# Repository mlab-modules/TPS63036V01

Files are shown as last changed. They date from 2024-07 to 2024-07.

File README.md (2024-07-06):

# TPS63036V01 -  TPS63036-Based  buck-boost converter 

The TPS63036V01 module is a highly efficient, single-inductor, buck-boost converter designed to provide a stable output voltage from varying input voltages. It integrates the Texas Instruments TPS63036 chip, making it suitable for applications requiring a compact, efficient power solution.

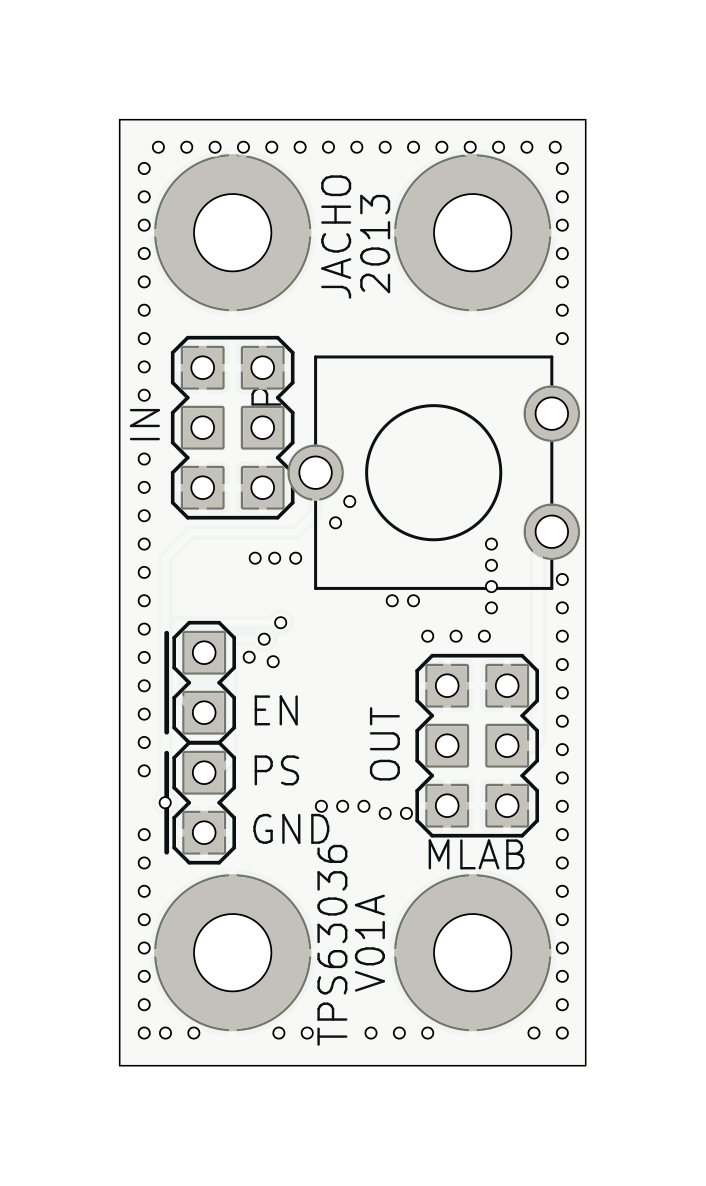
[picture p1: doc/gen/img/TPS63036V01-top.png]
TPS63036V01 top

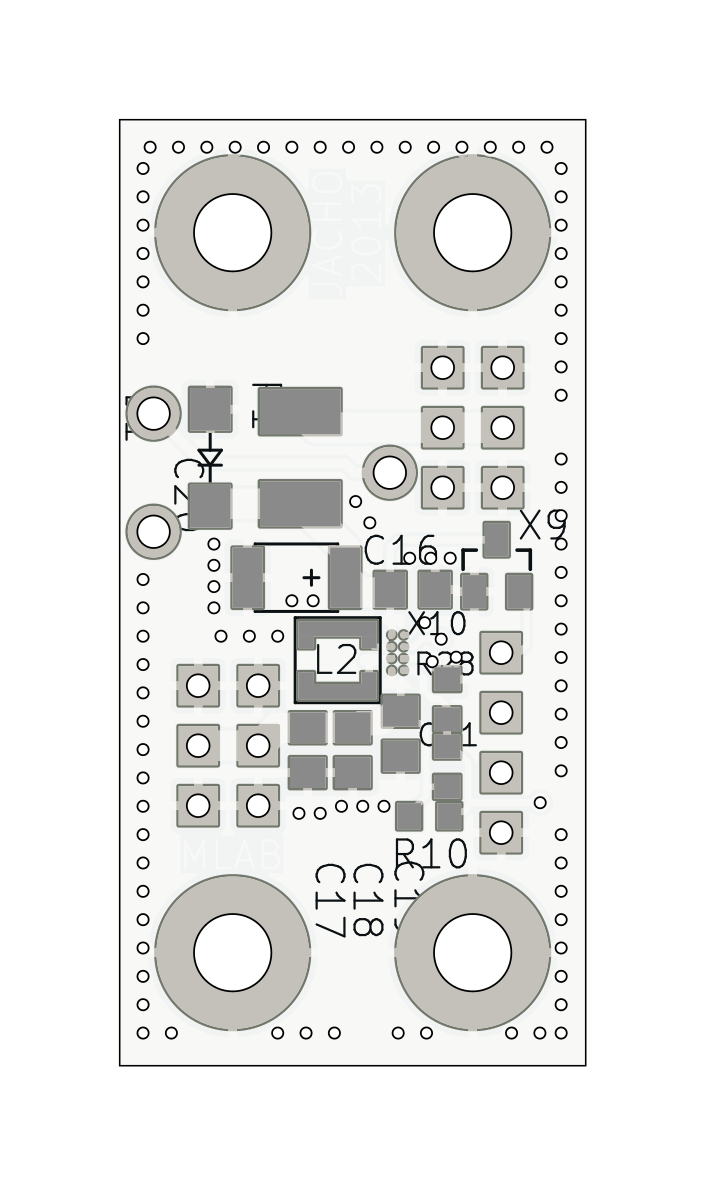
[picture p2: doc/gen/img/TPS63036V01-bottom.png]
TPS63036V01 bottom


## Features

- **Input Voltage Range:** 1.8V to 5.5V
- **Output Voltage:** 3.3V (adjustable between 1.2V and 5.5V)
- **Maximum Output Current:** 600 mA
- **Operating Frequency:** 2 MHz
- **High Efficiency:** Up to 85% at 3.6V input and 500mA load
- **Compact Size:** Miniature 3.0 × 3.0 mm footprint
- **Shielded Inductors:** LPS3015 series for low DCR and excellent current handling

## Components

### TPS63036 Buck-Boost Converter
- **Manufacturer:** Texas Instruments
- **Package:** 8-ball, 1.854 mm × 1.076 mm wafer chip-scale package (YFG)
- **Description:** The TPS63036 is a highly efficient single-inductor buck-boost converter. It supports both fixed and adjustable output voltages. The device operates with an input voltage range of 1.8V to 5.5V.

### LPS3015 Series Shielded Inductors
- **Manufacturer:** Coilcraft
- **Inductance Values:** Range from 1.0 µH to 330 µH
- **DCR (max):** 0.075 to 23.0 ohms
- **Current Rating:** Up to 2.35A
- **SRF (min):** 9 MHz
- **Dimensions:** 3.0 × 3.0 mm footprint, less than 1.5 mm tall

## Setup Instructions

1. **Input Connection:** Connect the input power supply between on input header. Ensure the input voltage is between 1.8V and 5.5V.
2. **Output Connection:** Connect the load to output header.
3. **Enable/Disable:** Use jumper SV1 to enable or disable the TPS63036.
4. **Power-Saving Mode:** Use jumper SV6 to enable (PWM/PSM) or disable (PWM) the power-saving mode.

## Performance Specifications

| Parameter | Condition | Min  | Typ  | Max  | Unit |
|---|---|---|---|---|---|
| Input Voltage | | 1.8  | 5.5  | | V |
| Output Voltage  | Vin = 4.2V, Iout = 500mA | 3.2  | 3.3  | 3.4  | V |
| Output Current  | Vin = 3.6V | 0 | 600  | | mA |
| Operating Freq. | | | 2000 | | kHz  |
| Efficiency | 3.6V in, 500mA load | | 85 | | % |
| Output Ripple | 3.6V in, 500mA load | | 25 | | mV |

## Additional Resources

- [TPS63036 Datasheet](https://www.ti.com/lit/ds/symlink/tps63036.pdf)
- [LPS3015 Inductor Datasheet](https://www.coilcraft.com/en-us/products/inductors/shielded/lps3015/)

## Contact

For support, contact MLAB at [support@mlab.cz](mailto:support@mlab.cz).

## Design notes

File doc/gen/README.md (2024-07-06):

# PCB

Board size: 19.81x40.13 mm (0.78x1.58 inches)

- This is the size of the rectangle that contains the board
- Thickness: 1.6 mm (63 mils)
- Material: FR4
- Finish: HAL
- Layers: 2
- Copper thickness: 35 µm

Solder mask: TOP / BOTTOM

- Color: Green

Silk screen: TOP / BOTTOM

- Color: White

# Important sizes

Clearance: 0.15 mm (6 mils)

Track width: 0.25 mm (10 mils)

- By design rules: 0.0 mm (0 mils)

Drill: 0.5 mm (20 mils)

- Vias: 0.5 mm (20 mils) [Design: 0.4 mm (16 mils)]
- Pads: 1.0 mm (39 mils)
- The above values are real drill sizes, they add 0.1 mm (4 mils) to plated holes (PTH)

Via: 0.81/0.4 mm (32/16 mils)

- By design rules: 0.5/0.3 mm (20/12 mils)
- Micro via: yes [0.2/0.1 mm (8/4 mils)]
- Buried/blind via: yes
- Total: 100 (thru: 100 buried/blind: 0 micro: 0)

Outer Annular Ring: 0.15 mm (6 mils)

- By design rules: 0.33 mm (13 mils)

Eurocircuits class: 6B
- Using min drill 0.5 mm for an OAR of 0.15 mm

# General stats

Components count: (SMD/THT)

- Top: 0/9 (THT)
- Bottom: 0/13 (THT)

Defined tracks:

Used tracks:

- 0.25 mm (10 mils) (61) defined: no
- 0.3 mm (12 mils) (13) defined: no
- 0.41 mm (16 mils) (9) defined: no
- 1.02 mm (40 mils) (7) defined: no
- 1.27 mm (50 mils) (14) defined: no

Defined vias:

Used vias:

- 0.81/0.4 mm (32/16 mils) (Count: 100, Aspect: 2.0 A) defined: no

Holes (excluding vias):

- 0.89 mm (35 mils) (16)
- 1.3 mm (51 mils) (3)
- 3.2 mm (126 mils) (4)

Oval holes:

Drill tools (including vias and computing adjusts and rounding):

- 0.5 mm (20 mils) (100)
- 1.0 mm (39 mils) (16)
- 1.4 mm (55 mils) (3)
- 3.3 mm (130 mils) (4)

Solder paste stats:

Using a paste with 87.75 % alloy, that has an specific gravity for the alloy of 7.4 g/cm³
and 1.0 g/cm³ for the flux. This paste has an specific gravity of  4.15 g/cm³.

The stencil thickness is  0.12 mm.

| Side | Pads with paste | Area [mm²] | Paste [g] |
|---|---|---|---|
| Total  | 29 | 57.42 | 0.29 |

Note: this is just an approximation to the theoretical value. Margins of the solder mask and waste aren't computed.

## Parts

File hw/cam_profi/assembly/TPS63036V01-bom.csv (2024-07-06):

Component | Description | Part | References | Value | Footprint | Quantity Per PCB | Datasheet
1 |  | C0603 | C21 | 10p | 0603 | 1
2 |  | C0805 | C16C17C18C19 | 10uF | C0805 | 4
3 |  | B | C20 | 47uF | B | 1
4 |  | D-OB.SMA | D1 | D-OB.SMA | SMA | 1
5 |  | LPS3015 | L2 | LPS3015-152MLC | LPS3015 | 1
6 |  | POJISTKA_1812 | P1 | POJISTKA_1812 | 1812 | 1
7 |  | TRIM_CA9MTV10 | P2 | TRIM_CA9MTV10 | TRIM_CA9MTV10 | 1
8 |  | R0603 | R28 | 51k1 | 0603 | 1
9 |  | R0603 | R10 | 287k | 0603 | 1
10 |  | MA02-1 | SV1SV6 | MA02-1 | MA02-1 | 2
11 |  | MA03-2 | SV3SV5 | MA03-2 | MA03-2 | 2
12 |  | APX809-26SA | X9 | APX809-26SA | SOT23 | 1
13 |  | SROUB3M | X1X2X3X4 | SROUB3M | SROUB3M | 4
14 |  | TPS63036 | X10 | TPS63036 | DSBGA8 | 1

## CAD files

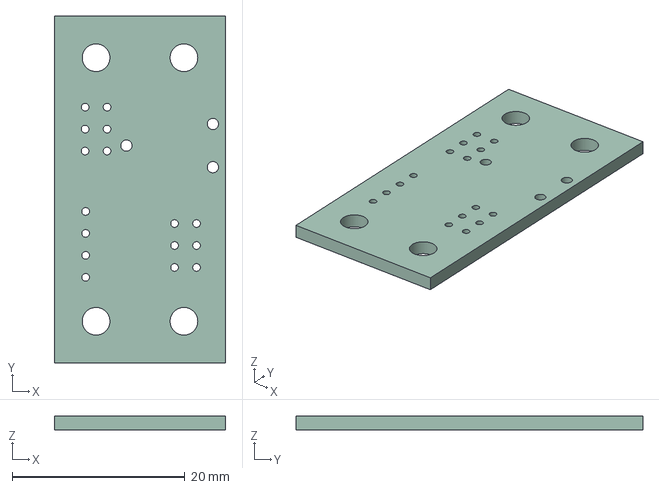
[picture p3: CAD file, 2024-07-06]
doc/gen/TPS63036V01.step
19.8 x 40.1 x 1.60 mm

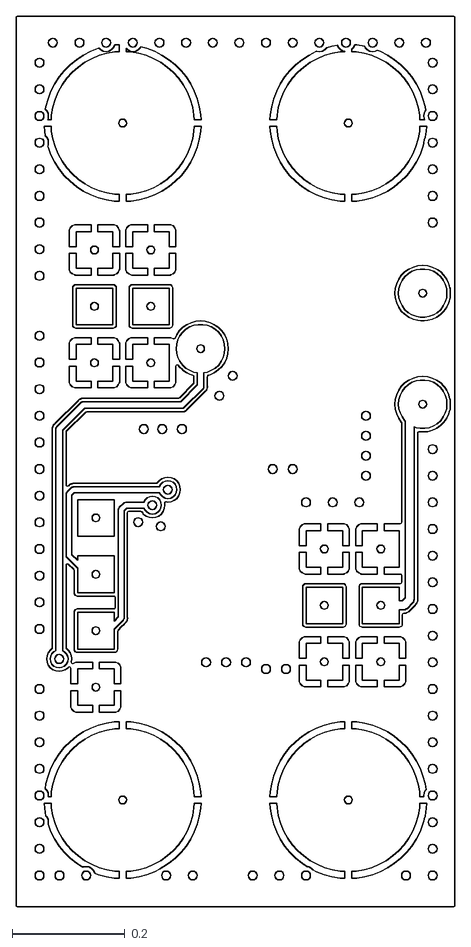
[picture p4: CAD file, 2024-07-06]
doc/gen/dxf/TPS63036V01-F_Cu.dxf
0.778 x 1.58

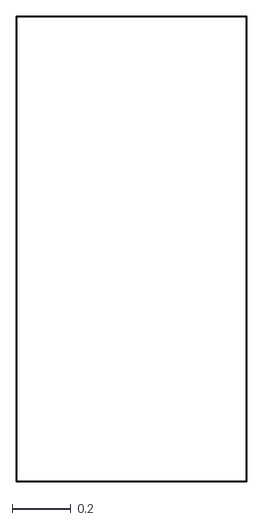
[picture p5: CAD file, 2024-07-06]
doc/gen/dxf/TPS63036V01-Edge_Cuts.dxf
0.782 x 1.58

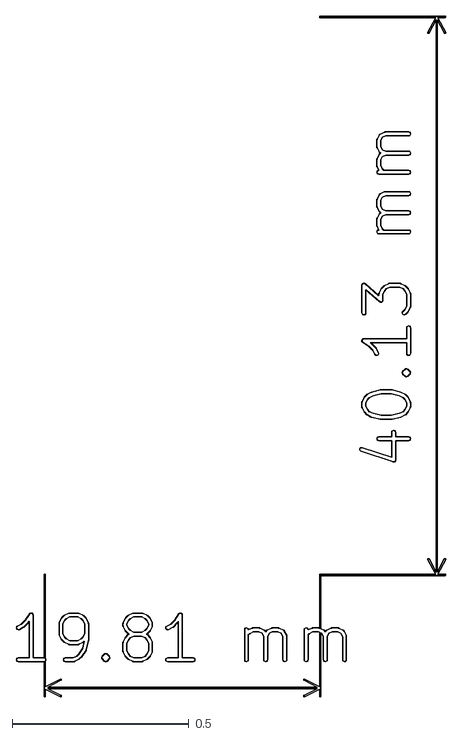
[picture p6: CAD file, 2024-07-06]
doc/gen/dxf/TPS63036V01-User_Comments.dxf
1.22 x 1.93

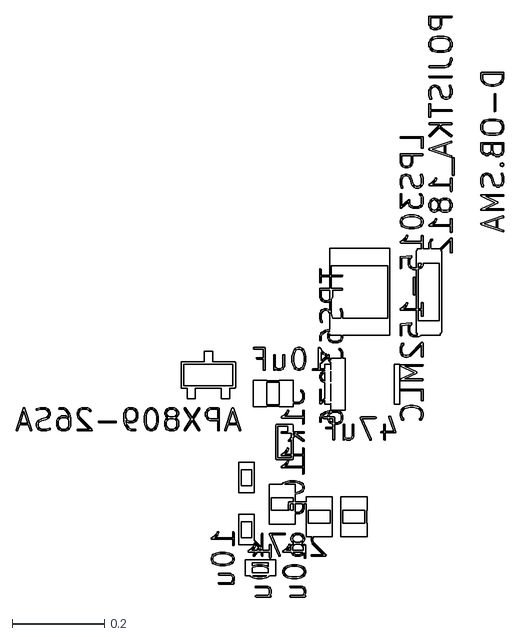
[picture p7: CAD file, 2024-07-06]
doc/gen/dxf/TPS63036V01-B_Fab.dxf
1.06 x 1.26

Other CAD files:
doc/gen/dxf/TPS63036V01-User_Eco2.dxf
doc/gen/dxf/TPS63036V01-User_8.dxf
doc/gen/dxf/TPS63036V01-User_5.dxf
doc/gen/dxf/TPS63036V01-F_Courtyard.dxf
doc/gen/dxf/TPS63036V01-Margin.dxf
doc/gen/dxf/TPS63036V01-F_Adhesive.dxf
doc/gen/dxf/TPS63036V01-User_1.dxf
doc/gen/dxf/TPS63036V01-User_6.dxf
doc/gen/dxf/TPS63036V01-User_3.dxf
doc/gen/dxf/TPS63036V01-User_2.dxf
doc/gen/dxf/TPS63036V01-B_Courtyard.dxf
doc/gen/dxf/TPS63036V01-B_Adhesive.dxf
doc/gen/dxf/TPS63036V01-User_7.dxf
doc/gen/dxf/TPS63036V01-B_Cu.dxf
doc/gen/dxf/TPS63036V01-B_Mask.dxf
doc/gen/dxf/TPS63036V01-B_Paste.dxf
doc/gen/dxf/TPS63036V01-B_Silkscreen.dxf
doc/gen/dxf/TPS63036V01-F_Fab.dxf
doc/gen/dxf/TPS63036V01-F_Mask.dxf
doc/gen/dxf/TPS63036V01-F_Paste.dxf
doc/gen/dxf/TPS63036V01-F_Silkscreen.dxf
doc/gen/dxf/TPS63036V01-User_4.dxf
doc/gen/dxf/TPS63036V01-User_9.dxf
doc/gen/dxf/TPS63036V01-User_Drawings.dxf
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

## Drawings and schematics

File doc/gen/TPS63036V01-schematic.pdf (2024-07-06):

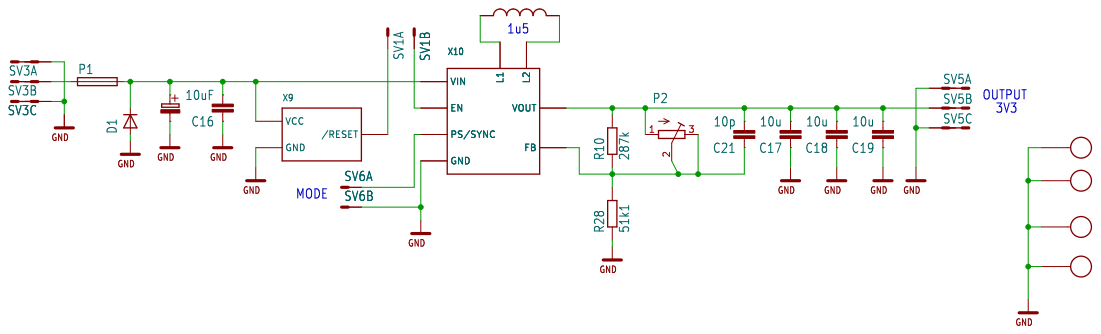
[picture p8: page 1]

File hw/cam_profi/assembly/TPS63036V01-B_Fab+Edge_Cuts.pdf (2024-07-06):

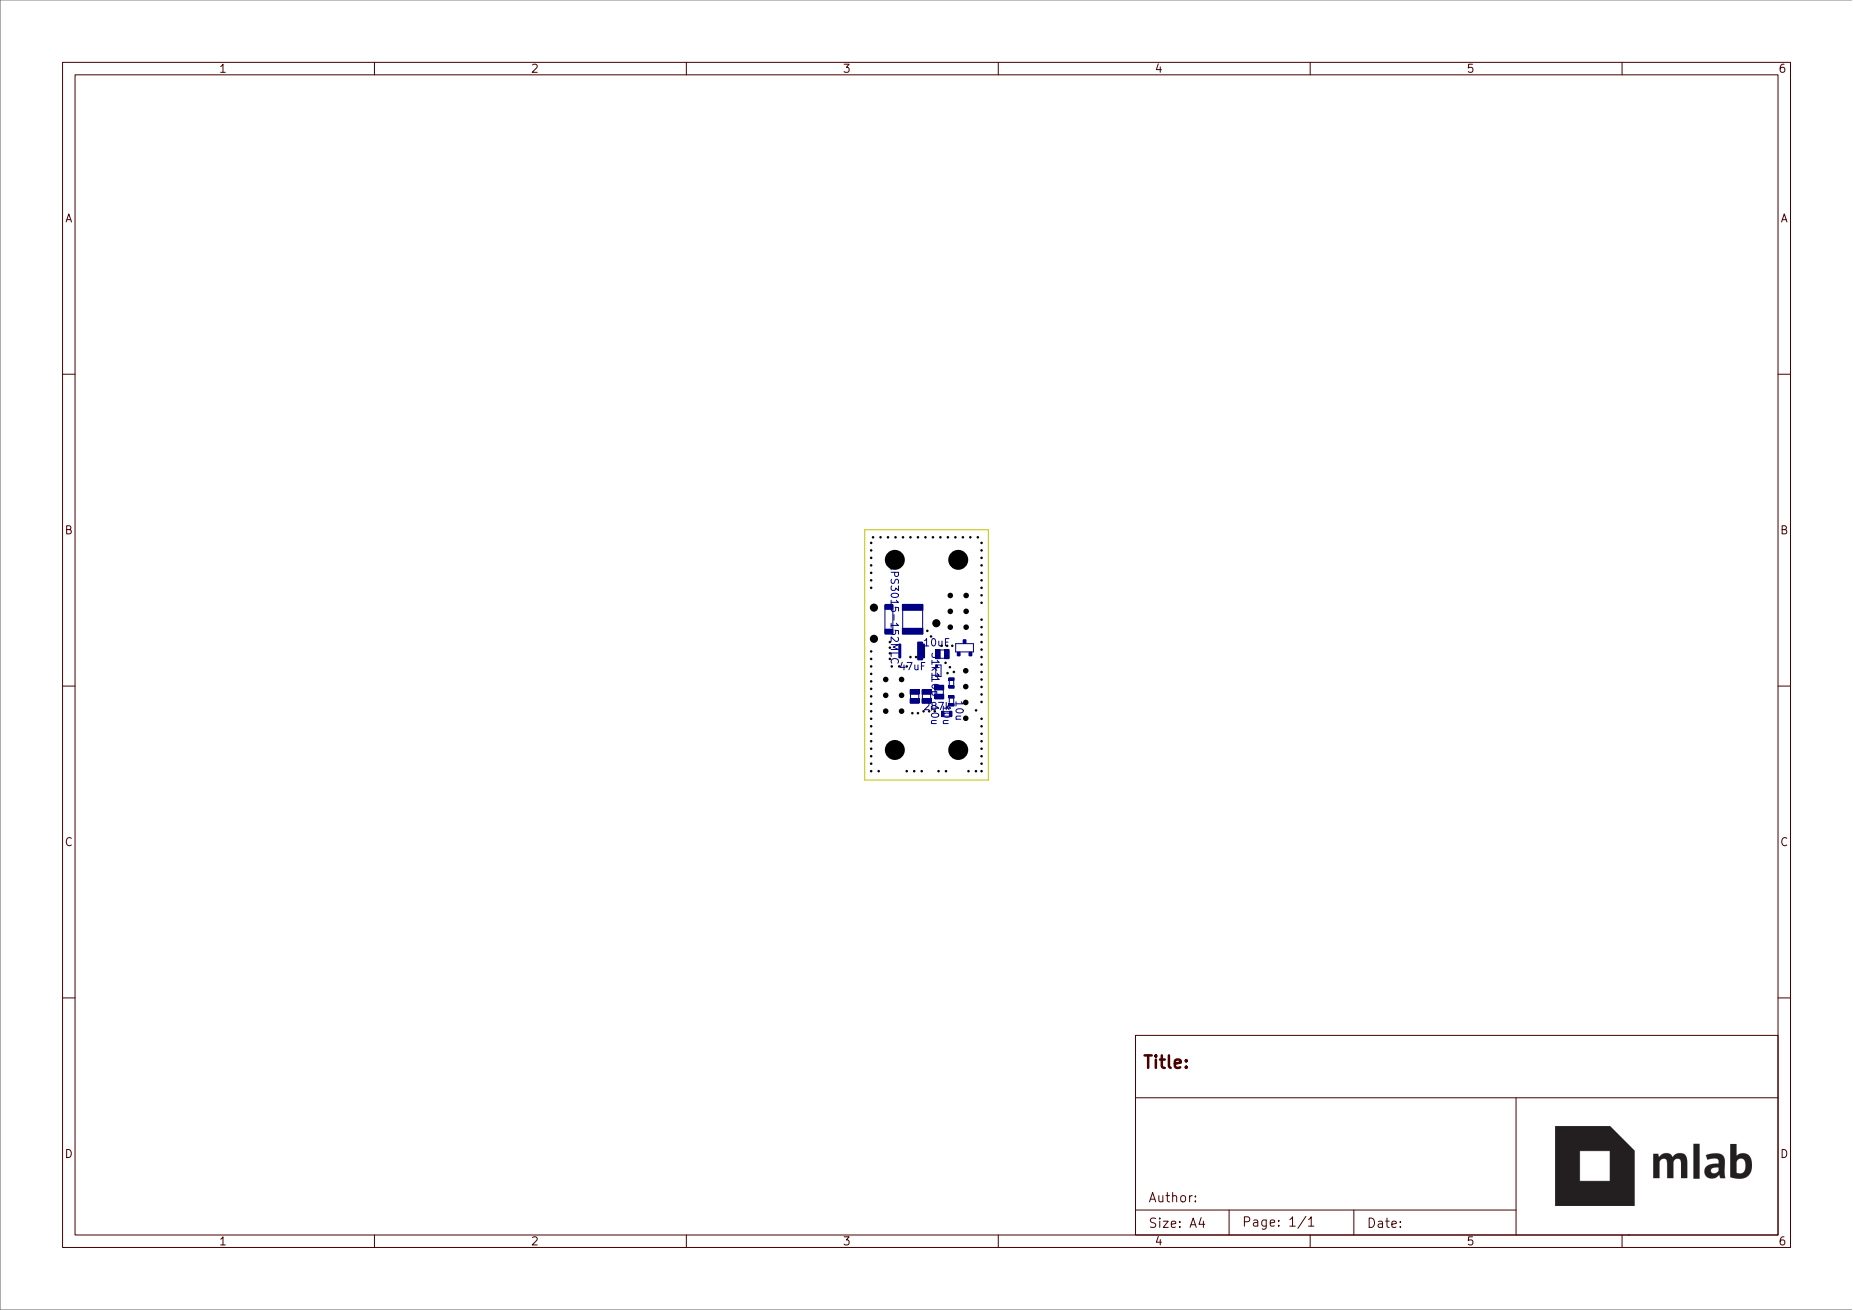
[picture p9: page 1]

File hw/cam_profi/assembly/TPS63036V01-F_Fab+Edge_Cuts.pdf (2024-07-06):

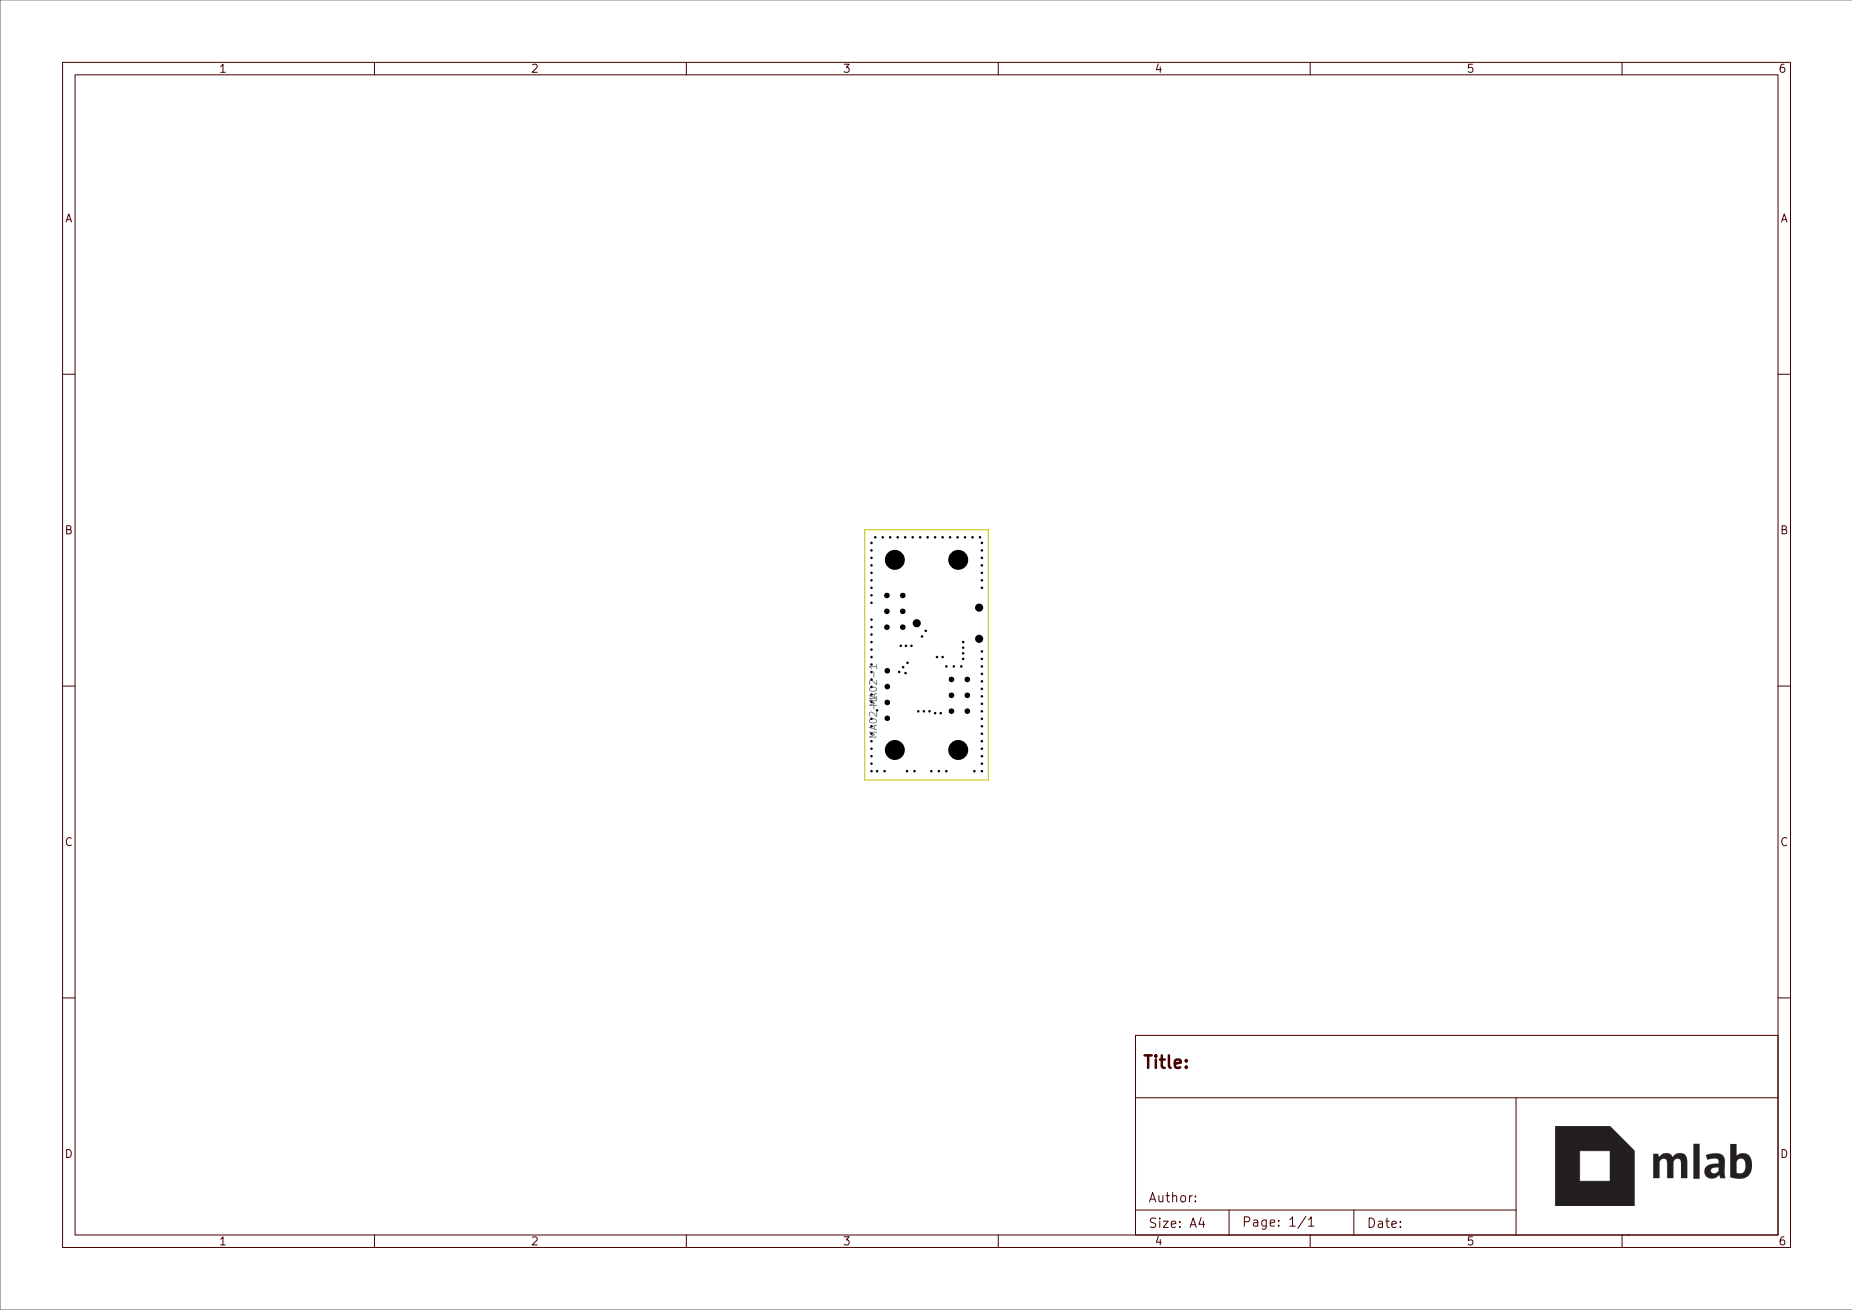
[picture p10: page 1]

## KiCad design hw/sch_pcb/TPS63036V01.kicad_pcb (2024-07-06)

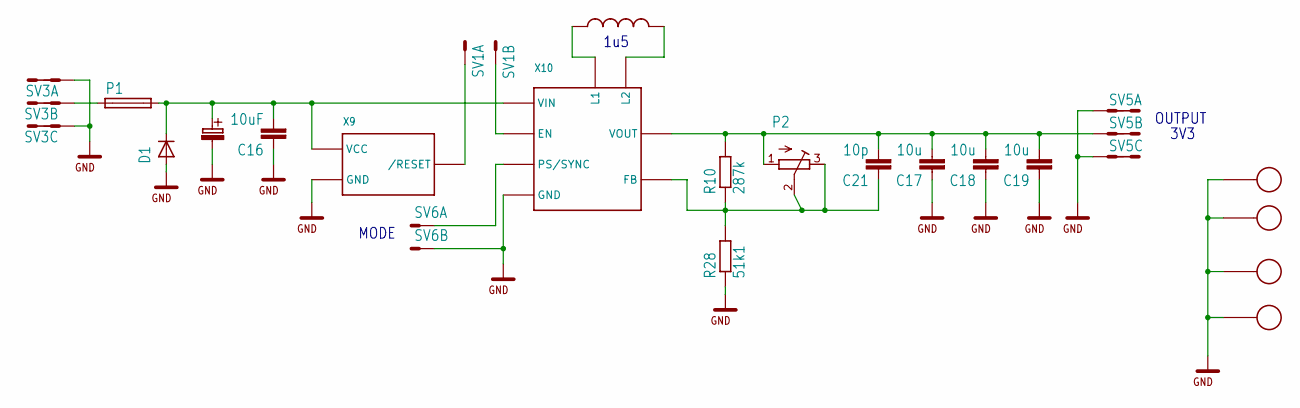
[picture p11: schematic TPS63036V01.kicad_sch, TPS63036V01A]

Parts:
C16: 10uF; C0805
C17, C18, C19: 10u; C0805
C20: 47uF; B
C21: 10p; 0603
D1: D-OB.SMA; SMA
L2: LPS3015-152MLC; LPS3015
P1: POJISTKA_1812; 1812
P2: TRIM_CA9MTV10
R10: 287k; 0603
R28: 51k1; 0603
SV1, SV6: MA02-1
SV3, SV5: MA03-2
X1, X2, X3, X4: SROUB3M
X9: APX809-26SA; SOT23
X10: TPS63036; DSBGA8

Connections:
+BAT2: C16.2, C20.+ (C_EL+), D1.K (C), P1.2, X9.3 (VCC), X10.A1 (VIN)
GND: C16.1, C17.1, C18.1, C19.1, C20.- (C_EL-), D1.A, R28.1, SV3.1, SV3.2, SV3.5, SV3.6, SV5.1, SV5.2, SV5.5, SV5.6, SV6.2, X1.P$1, X2.P$1, X3.P$1, X4.P$1, X9.1 (GND), X10.C2 (GND)
unnamed: SV1.1, X9.2 (/RESET)
unnamed: SV1.2, X10.A2 (EN)
unnamed: P1.1, SV3.3, SV3.4
unnamed: L2.1-1 (1), L2.1-2 (1), L2.1-3 (1), X10.B1 (L1)
unnamed: SV6.1, X10.B2 (PS/SYNC)
unnamed: L2.2-1 (2), L2.2-2 (2), L2.2-3 (2), X10.C1 (L2)
unnamed: C17.2, C18.2, C19.2, C21.2, P2.1, R10.2, SV5.3, SV5.4, X10.D1 (VOUT)
unnamed: C21.1, P2.2, P2.3, R10.1, R28.2, X10.D2 (FB)

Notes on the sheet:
MODE
3V3
1u5
OUTPUT

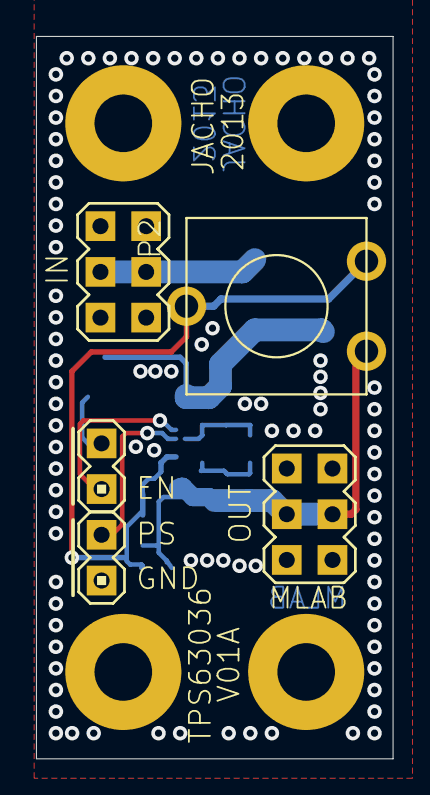
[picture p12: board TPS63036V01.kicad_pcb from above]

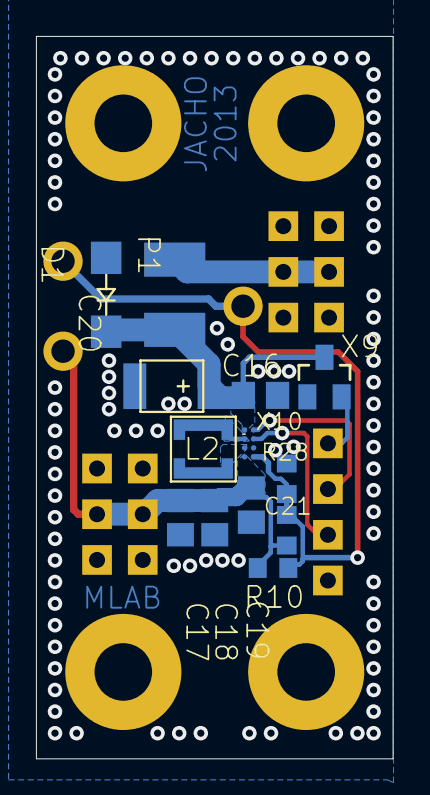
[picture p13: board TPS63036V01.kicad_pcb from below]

Board: 2 copper layers, 19.8 x 40.1 mm, 22 parts (13 on the bottom side), 10 nets.

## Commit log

2023-04-01 Adding force option to enable splitting in not fresh copy of Modules repository.
    [untitled.brd, untitled.sch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]
2024-07-06 Convert Eagle project to KiCADv7.
    [TPS63036V01.kicad_pcb, TPS63036V01.kicad_sch, untitled.brd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]
2024-07-06 Update actions products
    [TPS63036V01-B_Adhesive.dxf, TPS63036V01-B_Courtyard.dxf, TPS63036V01-B_Cu.dxf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]
